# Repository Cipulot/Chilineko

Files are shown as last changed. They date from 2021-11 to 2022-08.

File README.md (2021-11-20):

# Chilineko

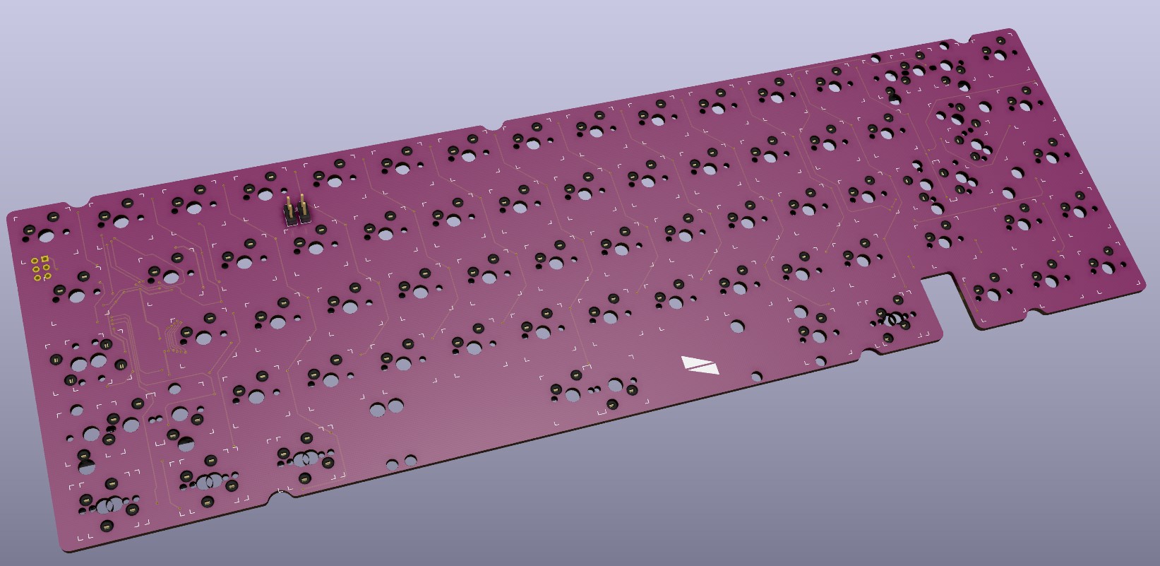
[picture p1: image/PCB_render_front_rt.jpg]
Chilineko Front

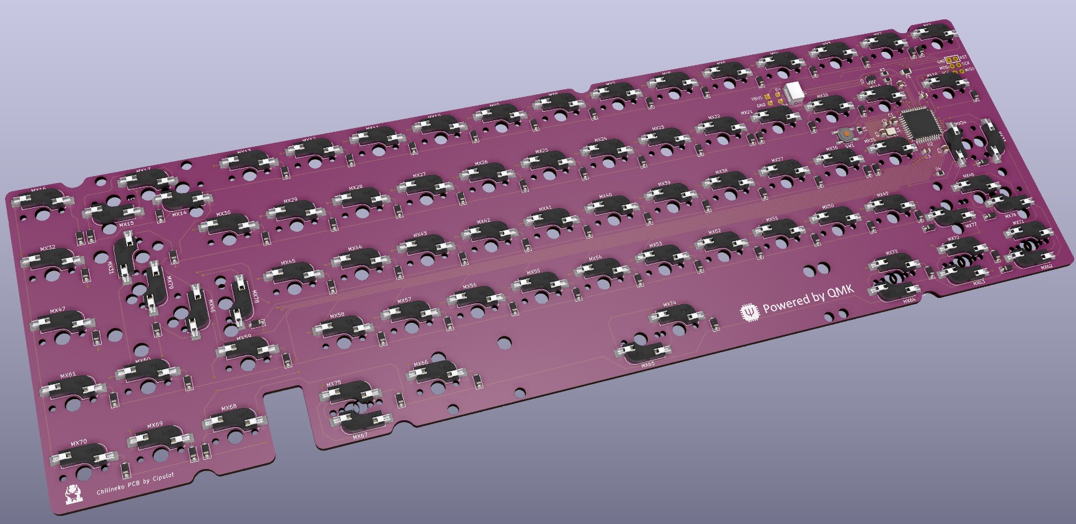
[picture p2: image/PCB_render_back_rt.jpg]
Chilineko Back


## Features

- Single piece tray case
- O-ring gasket mount (Friction fit)
- [Unified Daughterboard](https://github.com/ai03-2725/Unified-Daughterboard)
- QMK firmware and VIA
- PCB designed with KiCAD 5.1.10

## Layouts

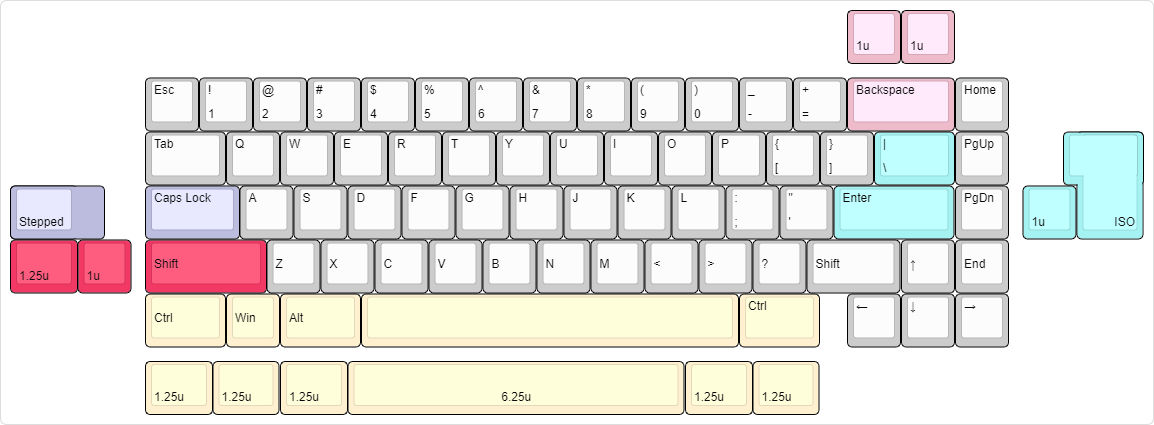
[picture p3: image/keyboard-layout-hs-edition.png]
Chilineko layouts


## Notes

- All files are to be used at your own risk
- As for stabilizers, only PCB snap-ins are supported

Read the files provided in the Resources section for further information.

## Resources

- Introductory document and PCB Order guide [here](https://drive.google.com/drive/folders/1Ks_figqYfMSzfUTn7lY1eMxK4qDpxoYU?usp=sharing)
- Personal KiCad Part Collection with already included components from most used one in keyboard [here](https://github.com/cipulot/cipulot_kicad_parts) (already included as a submodule in this repository)

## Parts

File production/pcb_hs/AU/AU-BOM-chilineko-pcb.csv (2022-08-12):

Comment | Designator | Footprint | LCSC
16MHz | Y1 | Crystal_SMD_3225-4Pin_3.2x2.5mm | C13738
JST SH 4-pin | J1 | JST_SH_SM04B-SRSS-TB_1x04-1MP_P1.00mm_Horizontal | C145956
10u | C4 | C_0805_2012Metric | C15850
10k | R1,R4 | R_0805_2012Metric | C17414
22 | R2,R3 | R_0805_2012Metric | C17561
22p | C5,C6 | C_0805_2012Metric | C1804
1u | MX1,MX10,MX11,MX12,MX13,MX14,MX15,MX16,MX17,MX18,MX19,MX2,MX20,MX21,MX22,MX23,MX24,MX25,MX26,MX27,MX28,MX29,MX3,MX30,MX31,MX32,MX33,MX34,MX35,MX36,MX37,MX38,MX39,MX4,MX40,MX41,MX42,MX43,MX44,MX45,MX46,MX47,MX48,MX49,MX5,MX50,MX51,MX52,MX53,MX54,MX55,MX56,MX57,MX58,MX59,MX6,MX60,MX61,MX62,MX63,MX64,MX65,MX66,MX67,MX68,MX69,MX7,MX70,MX71,MX72,MX73,MX74,MX75,MX76,MX77,MX78,MX79,MX8,MX9 | SW_MX_HS_1u | C2803348
1u | C7 | C_0805_2012Metric | C28323
Reset | SW1 | SW_SPST_TL3342 | C318884
ATmega32U4-AU | U2 | TQFP-44_10x10mm_P0.8mm | C44854
0.1u | C1,C2,C3 | C_0805_2012Metric | C49678
500mA | F1 | Fuse_1206_3216Metric | C70076
1N4148 | D1,D10,D11,D12,D13,D14,D15,D16,D17,D18,D19,D2,D20,D21,D22,D23,D24,D25,D26,D27,D28,D29,D3,D30,D31,D32,D33,D34,D35,D36,D37,D38,D39,D4,D40,D41,D42,D43,D44,D45,D46,D47,D48,D49,D5,D50,D51,D52,D53,D54,D55,D56,D57,D58,D59,D6,D60,D61,D62,D63,D64,D65,D66,D67,D68,D69,D7,D70,D8,D9 | D_SOD-123 | C81598
SRV05-4 | U1 | SOT-23-6 | C85364

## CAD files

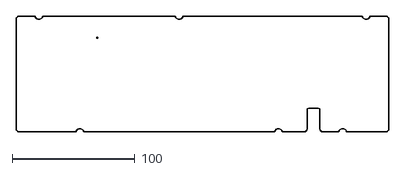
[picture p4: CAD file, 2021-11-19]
pcb_hs/pcb-outline.dxf
303.8 x 94.2

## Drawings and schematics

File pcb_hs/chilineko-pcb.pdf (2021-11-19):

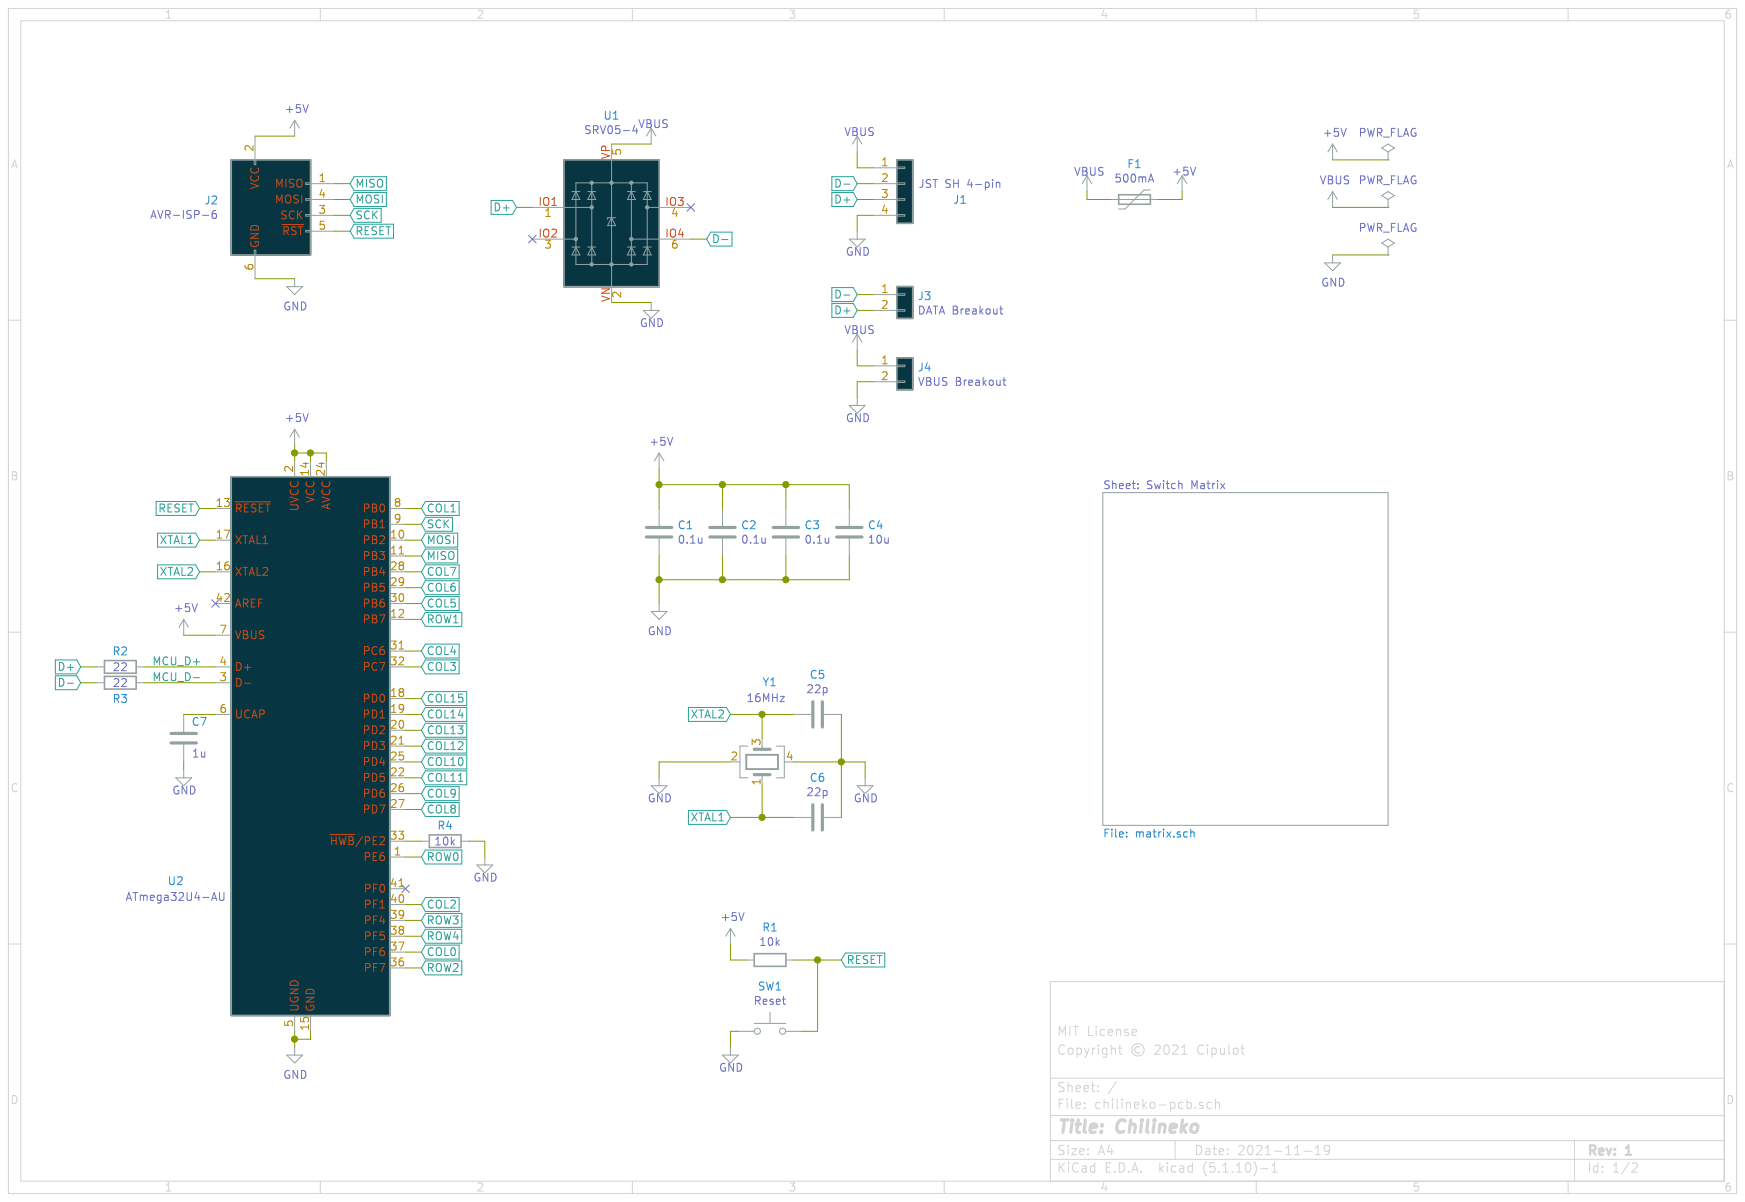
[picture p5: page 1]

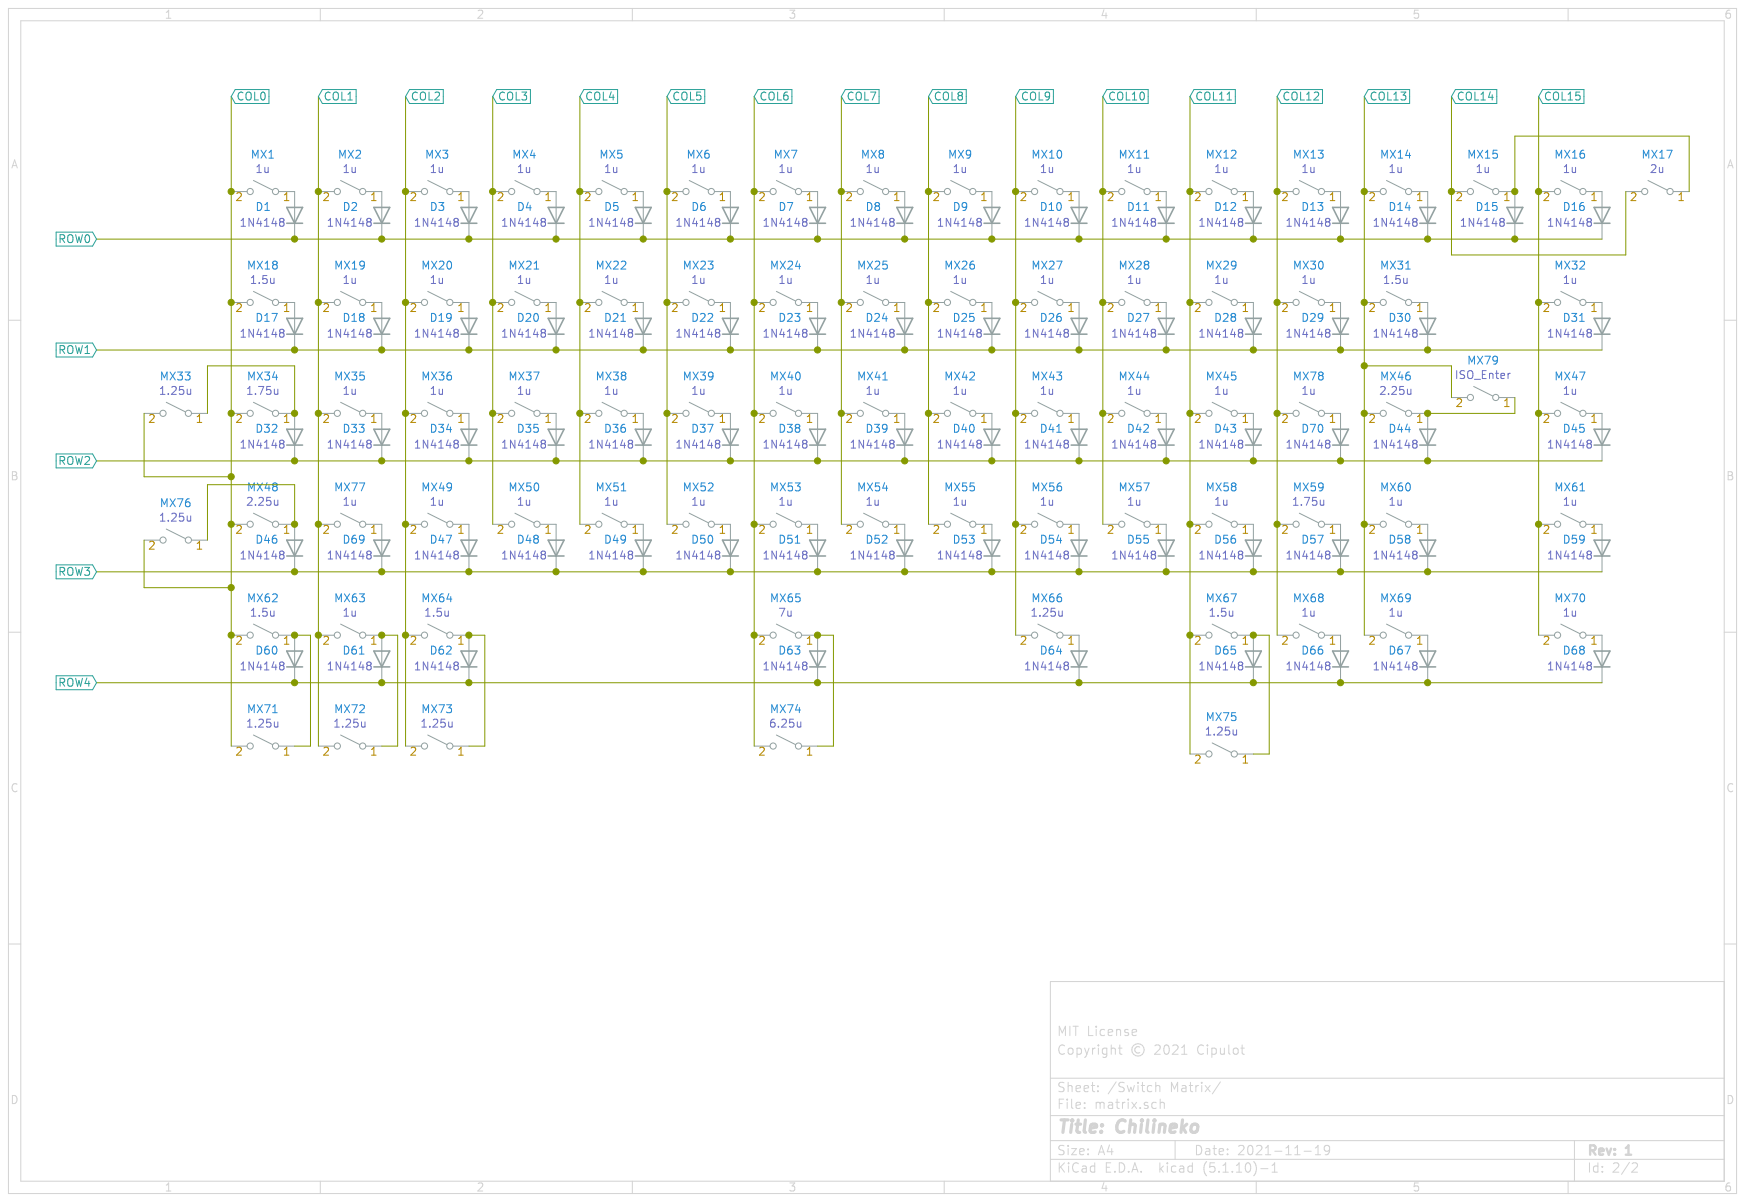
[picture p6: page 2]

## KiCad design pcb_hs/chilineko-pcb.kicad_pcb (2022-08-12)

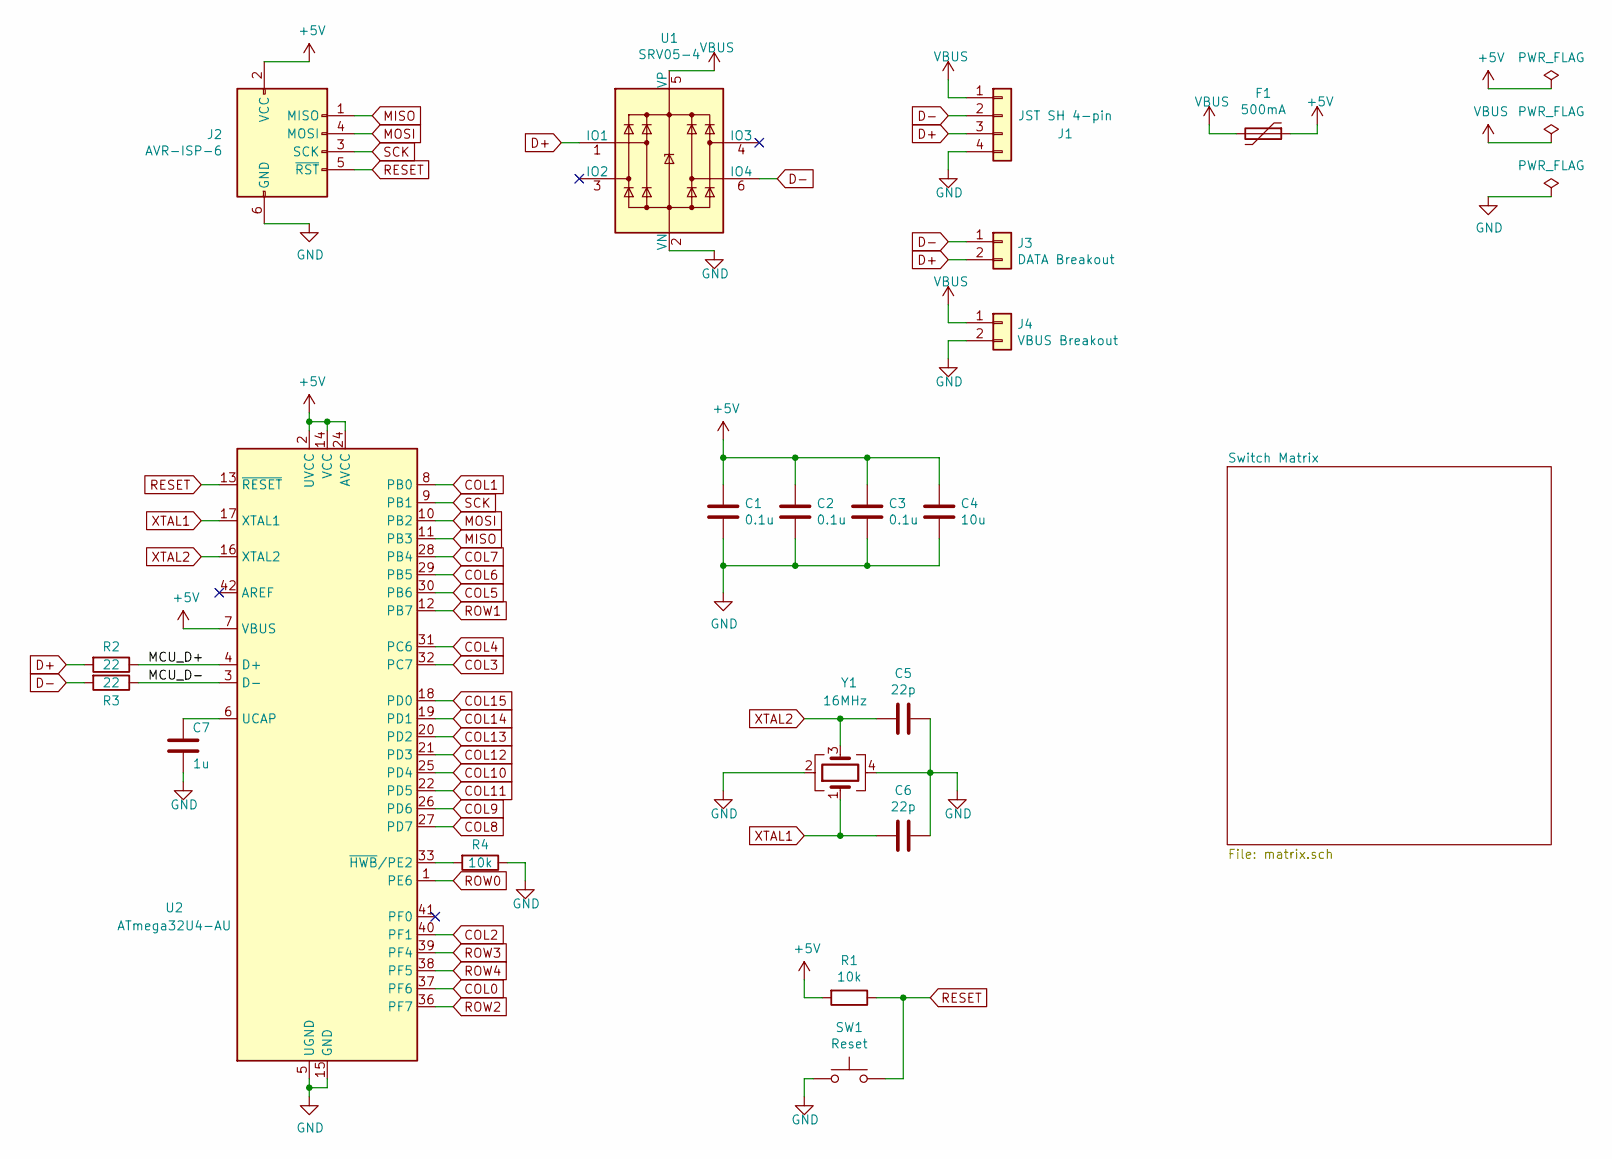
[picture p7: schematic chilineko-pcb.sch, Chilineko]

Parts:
C1, C2, C3: 0.1u; C_0805_2012Metric; LCSC Part # C49678
C4: 10u; C_0805_2012Metric; LCSC Part # C15850
C5, C6: 22p; C_0805_2012Metric; LCSC Part # C1804
C7: 1u; C_0805_2012Metric; LCSC Part # C28323
F1: 500mA; Fuse_1206_3216Metric; LCSC Part # C70076
J1: JST SH 4-pin; JST_SH_SM04B-SRSS-TB_1x04-1MP_P1.00mm_Horizontal; LCSC Part # C160404
J2: AVR-ISP-6; Reset_Pretty
J3: DATA Breakout; PinHeader_1x02_P2.54mm_Vertical
J4: VBUS Breakout; PinHeader_1x02_P2.54mm_Vertical
R1, R4: 10k; R_0805_2012Metric; LCSC Part # C17414
R2, R3: 22; R_0805_2012Metric; LCSC Part # C17561
SW1: Reset; SW_SPST_TL3342; LCSC Part # C318884
U1: SRV05-4; SOT-23-6; LCSC Part # C85364
U2: ATmega32U4-AU; TQFP-44_10x10mm_P0.8mm; LCSC Part # C44854
Y1: 16MHz; Crystal_SMD_3225-4Pin_3.2x2.5mm; LCSC Part # C13738

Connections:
+5V: C1.1, C2.1, C3.1, C4.1, F1.1, J2.2 (VCC), R1.2, U2.2 (UVCC), U2.7 (VBUS), U2.14 (VCC), U2.24 (AVCC), U2.34 (VCC), U2.44 (AVCC); also elsewhere on the board
/MCU_D+: R2.1, U2.4 (D+); also elsewhere on the board
/MCU_D-: R3.1, U2.3 (D-); also elsewhere on the board
COL0: U2.37 (PF6); also elsewhere on the board
COL1: U2.8 (PB0); also elsewhere on the board
COL2: U2.40 (PF1); also elsewhere on the board
COL3: U2.32 (PC7); also elsewhere on the board
COL4: U2.31 (PC6); also elsewhere on the board
COL5: U2.30 (PB6); also elsewhere on the board
COL6: U2.29 (PB5); also elsewhere on the board
COL7: U2.28 (PB4); also elsewhere on the board
COL8: U2.27 (PD7); also elsewhere on the board
COL9: U2.26 (PD6); also elsewhere on the board
COL10: U2.25 (PD4); also elsewhere on the board
COL11: U2.22 (PD5); also elsewhere on the board
COL12: U2.21 (PD3); also elsewhere on the board
COL13: U2.20 (PD2); also elsewhere on the board
COL14: U2.19 (PD1); also elsewhere on the board
COL15: U2.18 (PD0); also elsewhere on the board
D+: J1.3, J3.2, R2.2, U1.1 (IO1)
D-: J1.2, J3.1, R3.2, U1.6 (IO4)
GND: C1.2, C2.2, C3.2, C4.2, C5.1, C6.1, C7.1, J1.4, J2.6 (GND), J4.2, R4.1, SW1.1, U1.2 (VN), U2.5 (UGND), U2.15 (GND), U2.23 (GND), U2.35 (GND), U2.43 (GND), Y1.2, Y1.4; also elsewhere on the board
MISO: J2.1 (MISO), U2.11 (PB3); also elsewhere on the board
MOSI: J2.4 (MOSI), U2.10 (PB2); also elsewhere on the board
unnamed 24: C7.2, U2.6 (UCAP); also elsewhere on the board
unnamed 95: R4.2, U2.33 (~HWB~/PE2); also elsewhere on the board
unnamed 98: U2.41 (PF0); also elsewhere on the board
unnamed 99: U2.42 (AREF); also elsewhere on the board
RESET: J2.5 (~RST), R1.1, SW1.2, U2.13 (~RESET); also elsewhere on the board
ROW0: U2.1 (PE6); also elsewhere on the board
ROW1: U2.12 (PB7); also elsewhere on the board
ROW2: U2.36 (PF7); also elsewhere on the board
ROW3: U2.39 (PF4); also elsewhere on the board
ROW4: U2.38 (PF5); also elsewhere on the board
SCK: J2.3 (SCK), U2.9 (PB1); also elsewhere on the board
VBUS: F1.2, J1.1, J4.1, U1.5 (VP)
XTAL1: C6.2, U2.17 (XTAL1), Y1.1; also elsewhere on the board
XTAL2: C5.2, U2.16 (XTAL2), Y1.3; also elsewhere on the board

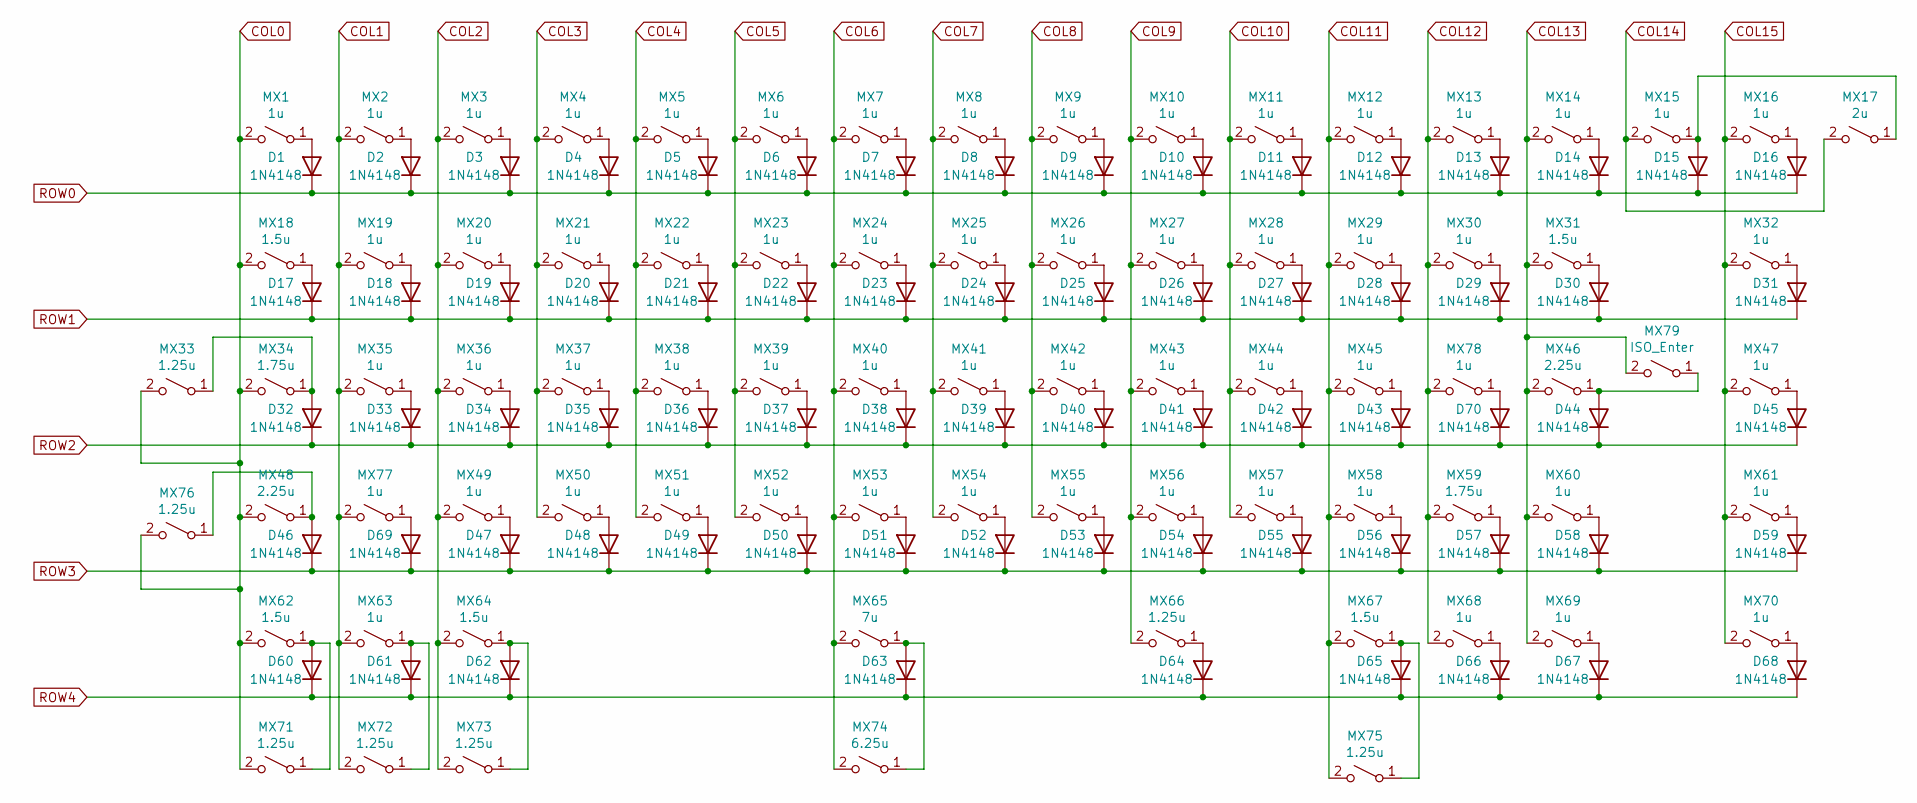
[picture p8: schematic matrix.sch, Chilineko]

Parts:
D1, D2, D3, D4, D5, D6, D7, D8, D9, D10, D11, D12, D13, D14, D15, D16, D17, D18, D19, D20, D21, D22, D23, D24, D25, D26, D27, D28, D29, D30, D31, D32, D33, D34, D35, D36, D37, D38, D39, D40, D41, D42, D43, D44, D45, D46, D47, D48, D49, D50, D51, D52, D53, D54, D55, D56, D57, D58, D59, D60, D61, D62, D63, D64, D65, D66, D67, D68, D69, D70: 1N4148; D_SOD-123; LCSC Part # C81598
MX1, MX2, MX3, MX4, MX5, MX6, MX7, MX8, MX9, MX10, MX11, MX12, MX13, MX14, MX15, MX16, MX19, MX20, MX21, MX22, MX23, MX24, MX25, MX26, MX27, MX28, MX29, MX30, MX32, MX35, MX36, MX37, MX38, MX39, MX40, MX41, MX42, MX43, MX44, MX45, MX47, MX49, MX50, MX51, MX52, MX53, MX54, MX55, MX56, MX57, MX58, MX60, MX61, MX63, MX68, MX69, MX70, MX77, MX78: 1u; Kailh_socket_MX_flippin
MX17: 2u; Kailh_socket_MX_flippin
MX18, MX31, MX62, MX64, MX67: 1.5u; Kailh_socket_MX_flippin
MX33, MX66, MX71, MX72, MX73, MX75, MX76: 1.25u; Kailh_socket_MX_flippin
MX34, MX59: 1.75u; Kailh_socket_MX_flippin
MX46, MX48: 2.25u; Kailh_socket_MX_flippin
MX65: 7u; Kailh_socket_MX_flippin
MX74: 6.25u; Kailh_socket_MX_flippin
MX79: ISO_Enter; Kailh_socket_MX_flippin

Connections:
COL0: MX1.2 (B), MX18.2 (B), MX33.2 (B), MX34.2 (B), MX48.2 (B), MX62.2 (B), MX71.2 (B), MX76.2 (B); also elsewhere on the board
COL1: MX2.2 (B), MX19.2 (B), MX35.2 (B), MX63.2 (B), MX72.2 (B), MX77.2 (B); also elsewhere on the board
COL2: MX3.2 (B), MX20.2 (B), MX36.2 (B), MX49.2 (B), MX64.2 (B), MX73.2 (B); also elsewhere on the board
COL3: MX4.2 (B), MX21.2 (B), MX37.2 (B), MX50.2 (B); also elsewhere on the board
COL4: MX5.2 (B), MX22.2 (B), MX38.2 (B), MX51.2 (B); also elsewhere on the board
COL5: MX6.2 (B), MX23.2 (B), MX39.2 (B), MX52.2 (B); also elsewhere on the board
COL6: MX7.2 (B), MX24.2 (B), MX40.2 (B), MX53.2 (B), MX65.2 (B), MX74.2 (B); also elsewhere on the board
COL7: MX8.2 (B), MX25.2 (B), MX41.2 (B), MX54.2 (B); also elsewhere on the board
COL8: MX9.2 (B), MX26.2 (B), MX42.2 (B), MX55.2 (B); also elsewhere on the board
COL9: MX10.2 (B), MX27.2 (B), MX43.2 (B), MX56.2 (B), MX66.2 (B); also elsewhere on the board
COL10: MX11.2 (B), MX28.2 (B), MX44.2 (B), MX57.2 (B); also elsewhere on the board
COL11: MX12.2 (B), MX29.2 (B), MX45.2 (B), MX58.2 (B), MX67.2 (B), MX75.2 (B); also elsewhere on the board
COL12: MX13.2 (B), MX30.2 (B), MX59.2 (B), MX68.2 (B), MX78.2 (B); also elsewhere on the board
COL13: MX14.2 (B), MX31.2 (B), MX46.2 (B), MX60.2 (B), MX69.2 (B), MX79.2 (B); also elsewhere on the board
COL14: MX15.2 (B), MX17.2 (B); also elsewhere on the board
COL15: MX16.2 (B), MX32.2 (B), MX47.2 (B), MX61.2 (B), MX70.2 (B); also elsewhere on the board
unnamed: D1.2 (A), MX1.1 (A)
unnamed: D2.2 (A), MX2.1 (A)
unnamed: D3.2 (A), MX3.1 (A)
unnamed: D4.2 (A), MX4.1 (A)
unnamed: D5.2 (A), MX5.1 (A)
unnamed: D6.2 (A), MX6.1 (A)
unnamed: D7.2 (A), MX7.1 (A)
unnamed: D8.2 (A), MX8.1 (A)
unnamed: D9.2 (A), MX9.1 (A)
unnamed: D10.2 (A), MX10.1 (A)
unnamed: D11.2 (A), MX11.1 (A)
unnamed: D12.2 (A), MX12.1 (A)
unnamed: D13.2 (A), MX13.1 (A)
unnamed: D14.2 (A), MX14.1 (A)
unnamed: D15.2 (A), MX15.1 (A), MX17.1 (A)
unnamed: D16.2 (A), MX16.1 (A)
unnamed: D17.2 (A), MX18.1 (A)
unnamed: D18.2 (A), MX19.1 (A)
unnamed: D19.2 (A), MX20.1 (A)
unnamed: D20.2 (A), MX21.1 (A)
unnamed: D21.2 (A), MX22.1 (A)
unnamed: D22.2 (A), MX23.1 (A)
unnamed: D23.2 (A), MX24.1 (A)
unnamed: D24.2 (A), MX25.1 (A)
unnamed: D25.2 (A), MX26.1 (A)
unnamed: D26.2 (A), MX27.1 (A)
unnamed: D27.2 (A), MX28.1 (A)
unnamed: D28.2 (A), MX29.1 (A)
unnamed: D29.2 (A), MX30.1 (A)
unnamed: D30.2 (A), MX31.1 (A)
unnamed: D31.2 (A), MX32.1 (A)
unnamed: D32.2 (A), MX33.1 (A), MX34.1 (A)
unnamed: D33.2 (A), MX35.1 (A)
unnamed: D34.2 (A), MX36.1 (A)
unnamed: D35.2 (A), MX37.1 (A)
unnamed: D36.2 (A), MX38.1 (A)
unnamed: D37.2 (A), MX39.1 (A)
unnamed: D38.2 (A), MX40.1 (A)
unnamed: D39.2 (A), MX41.1 (A)
unnamed: D40.2 (A), MX42.1 (A)
unnamed: D41.2 (A), MX43.1 (A)
unnamed: D42.2 (A), MX44.1 (A)
unnamed: D43.2 (A), MX45.1 (A)
unnamed: D44.2 (A), MX46.1 (A), MX79.1 (A)
unnamed: D45.2 (A), MX47.1 (A)
unnamed: D46.2 (A), MX48.1 (A), MX76.1 (A)
unnamed: D47.2 (A), MX49.1 (A)
unnamed: D48.2 (A), MX50.1 (A)
unnamed: D49.2 (A), MX51.1 (A)
unnamed: D50.2 (A), MX52.1 (A)
unnamed: D51.2 (A), MX53.1 (A)
unnamed: D52.2 (A), MX54.1 (A)
unnamed: D53.2 (A), MX55.1 (A)
unnamed: D54.2 (A), MX56.1 (A)
unnamed: D55.2 (A), MX57.1 (A)
unnamed: D56.2 (A), MX58.1 (A)
unnamed: D57.2 (A), MX59.1 (A)
unnamed: D58.2 (A), MX60.1 (A)
unnamed: D59.2 (A), MX61.1 (A)
unnamed: D60.2 (A), MX62.1 (A), MX71.1 (A)
unnamed: D61.2 (A), MX63.1 (A), MX72.1 (A)
unnamed: D62.2 (A), MX64.1 (A), MX73.1 (A)
unnamed: D63.2 (A), MX65.1 (A), MX74.1 (A)
unnamed: D64.2 (A), MX66.1 (A)
unnamed: D65.2 (A), MX67.1 (A), MX75.1 (A)
unnamed: D66.2 (A), MX68.1 (A)
unnamed: D67.2 (A), MX69.1 (A)
unnamed: D68.2 (A), MX70.1 (A)
unnamed: D69.2 (A), MX77.1 (A)
unnamed: D70.2 (A), MX78.1 (A)
ROW0: D1.1 (K), D2.1 (K), D3.1 (K), D4.1 (K), D5.1 (K), D6.1 (K), D7.1 (K), D8.1 (K), D9.1 (K), D10.1 (K), D11.1 (K), D12.1 (K), D13.1 (K), D14.1 (K), D15.1 (K), D16.1 (K); also elsewhere on the board
ROW1: D17.1 (K), D18.1 (K), D19.1 (K), D20.1 (K), D21.1 (K), D22.1 (K), D23.1 (K), D24.1 (K), D25.1 (K), D26.1 (K), D27.1 (K), D28.1 (K), D29.1 (K), D30.1 (K), D31.1 (K); also elsewhere on the board
ROW2: D32.1 (K), D33.1 (K), D34.1 (K), D35.1 (K), D36.1 (K), D37.1 (K), D38.1 (K), D39.1 (K), D40.1 (K), D41.1 (K), D42.1 (K), D43.1 (K), D44.1 (K), D45.1 (K), D70.1 (K); also elsewhere on the board
ROW3: D46.1 (K), D47.1 (K), D48.1 (K), D49.1 (K), D50.1 (K), D51.1 (K), D52.1 (K), D53.1 (K), D54.1 (K), D55.1 (K), D56.1 (K), D57.1 (K), D58.1 (K), D59.1 (K), D69.1 (K); also elsewhere on the board
ROW4: D60.1 (K), D61.1 (K), D62.1 (K), D63.1 (K), D64.1 (K), D65.1 (K), D66.1 (K), D67.1 (K), D68.1 (K); also elsewhere on the board

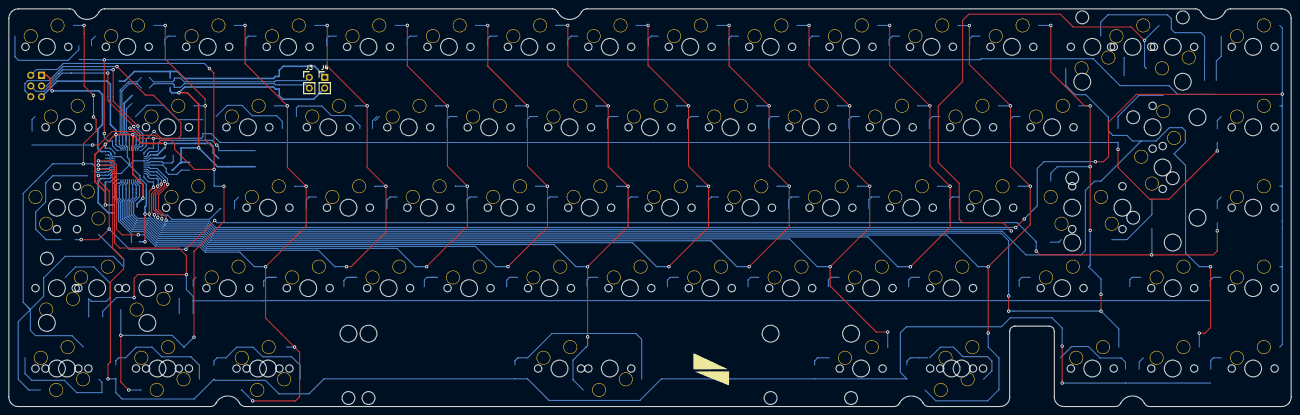
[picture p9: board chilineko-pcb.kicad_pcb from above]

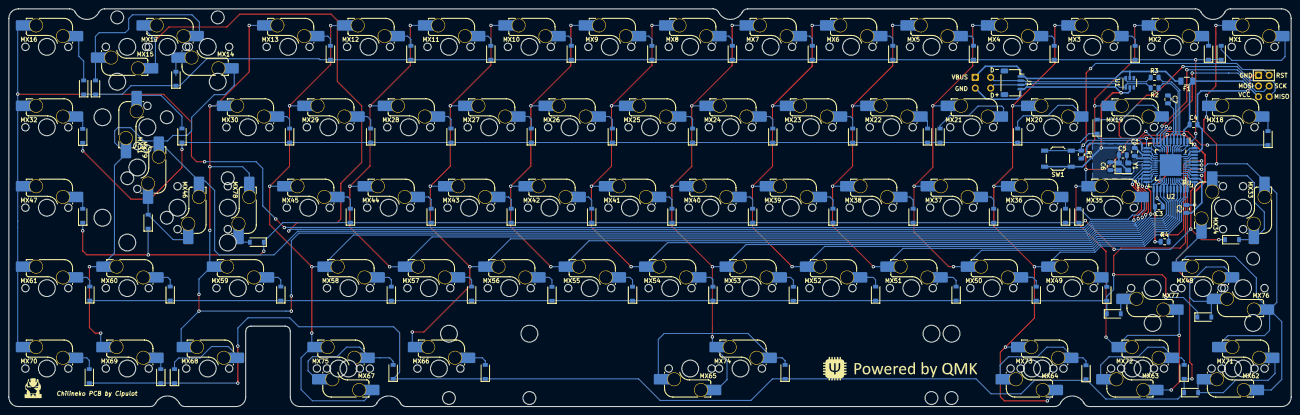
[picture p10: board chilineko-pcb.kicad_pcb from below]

Board: 2 copper layers, 303.8 x 94.2 mm, 170 parts (168 on the bottom side), 108 nets.

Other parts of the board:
MU: QFN-44-1EP_7x7mm_P0.5mm_EP5.15x5.15mm

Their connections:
+5V: MU.2, MU.7, MU.14, MU.24, MU.34, MU.44; also elsewhere on the board
/MCU_D+: MU.4; also elsewhere on the board
/MCU_D-: MU.3; also elsewhere on the board
COL0: MU.37; also elsewhere on the board
COL1: MU.8; also elsewhere on the board
COL2: MU.40; also elsewhere on the board
COL3: MU.32; also elsewhere on the board
COL4: MU.31; also elsewhere on the board
COL5: MU.30; also elsewhere on the board
COL6: MU.29; also elsewhere on the board
COL7: MU.28; also elsewhere on the board
COL8: MU.27; also elsewhere on the board
COL9: MU.26; also elsewhere on the board
COL10: MU.25; also elsewhere on the board
COL11: MU.22; also elsewhere on the board
COL12: MU.21; also elsewhere on the board
COL13: MU.20; also elsewhere on the board
COL14: MU.19; also elsewhere on the board
COL15: MU.18; also elsewhere on the board
GND: MU.5, MU.15, MU.23, MU.35, MU.43, MU.45; also elsewhere on the board
MISO: MU.11; also elsewhere on the board
MOSI: MU.10; also elsewhere on the board
unnamed 24: MU.6; also elsewhere on the board
unnamed 95: MU.33; also elsewhere on the board
unnamed 98: MU.41; also elsewhere on the board
unnamed 99: MU.42; also elsewhere on the board
RESET: MU.13; also elsewhere on the board
ROW0: MU.1; also elsewhere on the board
ROW1: MU.12; also elsewhere on the board
ROW2: MU.36; also elsewhere on the board
ROW3: MU.39; also elsewhere on the board
ROW4: MU.38; also elsewhere on the board
SCK: MU.9; also elsewhere on the board
XTAL1: MU.17; also elsewhere on the board
XTAL2: MU.16; also elsewhere on the board

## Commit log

2021-11-19 Add submodule
    Submodule containing kicad files and resources
2021-11-19 Gerber .zip folder name change
2021-11-19 Update lib references
    [chilineko-pcb.kicad_pcb, chilineko-pcb.sch]
2021-11-19 Update of readme and fix in 3d render
    [chilineko-pcb.kicad_pcb]
2021-11-20 Update of PCB
    Addition of double footprint for MCU. Now the board can be populated with both ATMEGA32U4-AU and ATMEGA32U4-MU.
    [chilineko-pcb.kicad_pcb]
2021-11-20 Separation of BOM and CPL files
    Separation of files for production based on which MCU package is used.
    [jlcpcb-chilineko-pcb-AU.csv, jlcpcb-chilineko-pcb-MU.csv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]
2021-11-29 Addition of MUR variant production files
    [jlcpcb-chilineko-pcb-MUR.csv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]
2022-08-12 Update to include HS socket in assembly files
    [AU-BOM-chilineko-pcb.csv, MU-BOM-chilineko-pcb.csv, MUR-BOM-chilineko-pcb.csv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]

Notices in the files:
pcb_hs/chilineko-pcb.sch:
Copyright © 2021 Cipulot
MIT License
